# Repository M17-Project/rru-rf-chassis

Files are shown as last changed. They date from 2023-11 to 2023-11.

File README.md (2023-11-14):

[][cc-by-nc-sa]

# rru-rf-chassis
Milled aluminum chassis for the [RRU RF board](https://github.com/M17-Project/rru-rf-hw).

## License
This work is licensed under a
[Creative Commons Attribution-NonCommercial-ShareAlike 4.0 International License][cc-by-nc-sa].

[][cc-by-nc-sa]

[cc-by-nc-sa]: http://creativecommons.org/licenses/by-nc-sa/4.0/
[cc-by-nc-sa-image]: https://licensebuttons.net/l/by-nc-sa/4.0/88x31.png
[cc-by-nc-sa-shield]: https://img.shields.io/badge/License-CC%20BY--NC--SA%204.0-lightgrey.svg

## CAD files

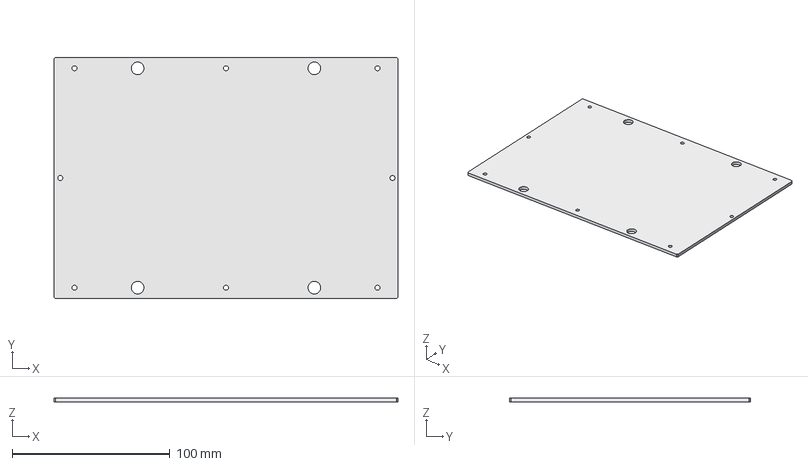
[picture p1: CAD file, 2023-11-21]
lid.step
218.0 x 153.0 x 2.50 mm

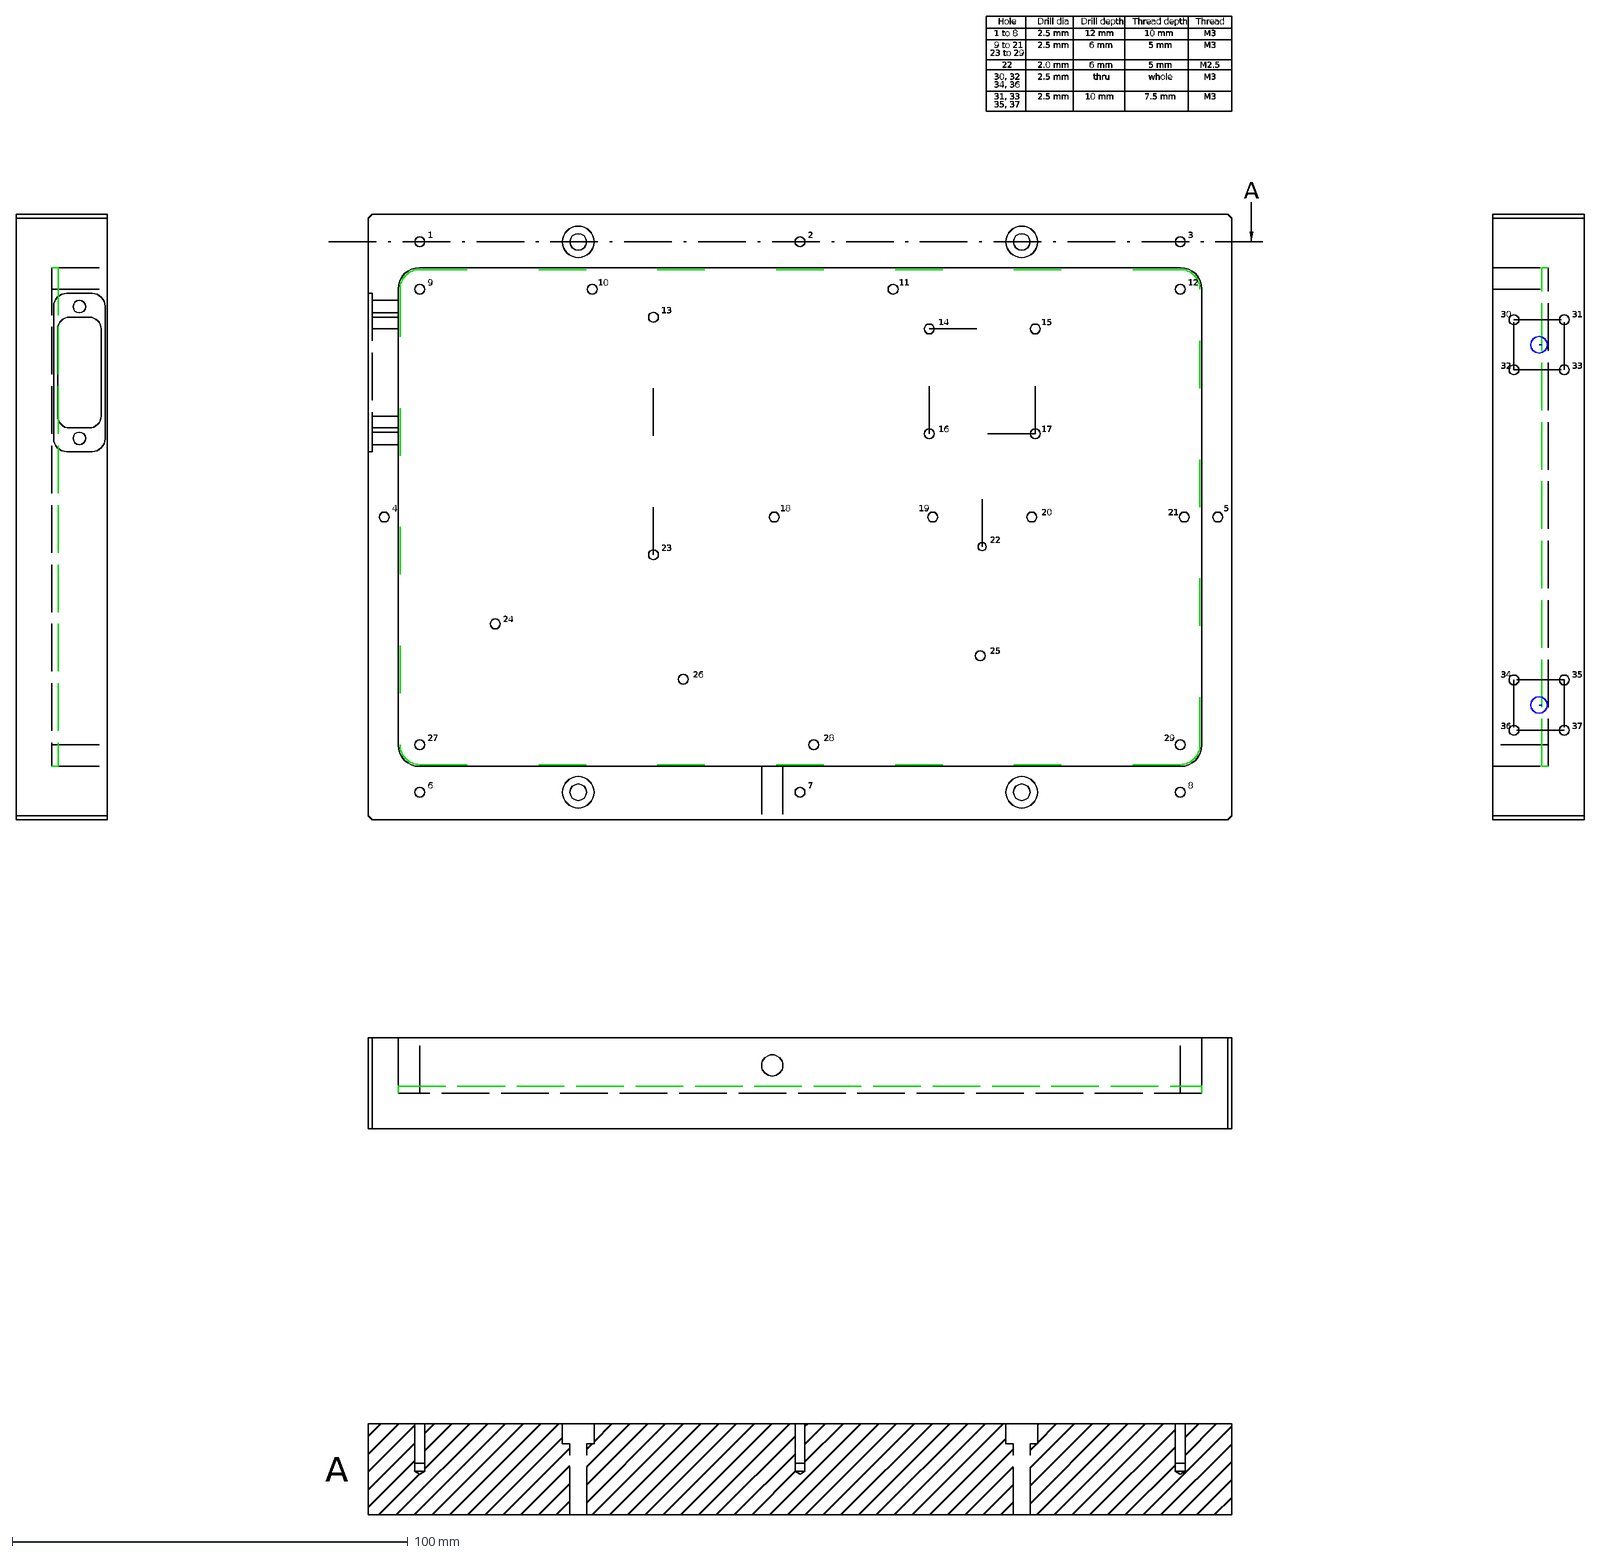
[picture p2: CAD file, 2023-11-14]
base.dxf
A
1
2
3
4
5
6
7
8
9
10
11
12
13
14
15
16
17
23
18
19
20
21
22
24
25
26
27
28
29
30
31
32
33
34
35
36
37
Hole
Drill dia
Drill depth
Thread depth
Thread
1 to 8
2.5 mm
12 mm
10 mm
M3
9 to 21
5 mm
6 mm
23 to 29
30, 32
34, 36
31, 33
35, 37
2.0 mm
M2.5
thru
whole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

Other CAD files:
lid.FCStd
lid.dxf

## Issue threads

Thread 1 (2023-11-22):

DA-15 connector

sp5wwp, 2023-11-22:
The hole for DA-15 connector `DA15S064TLF` needs to be trimmed slightly, it's too small. Dimensions read from Mouser's 3D model are inaccurate. Since the connector can be forced in, I'm tagging this as an `enhancement` instead of `bug`.

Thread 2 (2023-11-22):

Power supply pin

sp5wwp, 2023-11-22:
The power supply feed through capacitor `2499-003-X5W0-103ZLF` fits in nicely but, is not held in place strong enough. The hole needs to be threaded.

Capacitor's pin inside the chassis is short, much less than a millimeter.

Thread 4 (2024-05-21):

M4 mounting bolt depth

sp5wwp, 2024-05-21:
18mm of material below the bolt seems too much. For a standard M4x20 bolt, it leaves only 2mm of thread. Subtracting the gap filled with thermal grease, that leaves less than 2mm. I'd deepen the counterbore hole by 1mm.

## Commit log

2023-11-02 initial upload
    [base.dxf]
2023-11-03 added 4 mounting holes
    [base.dxf]
2023-11-03 update holes
    [base.dxf]
2023-11-03 left side view
    [base.dxf]
2023-11-06 added a hole for DA15 connector
    [base.dxf]
2023-11-06 updated pcb outline
    [base.dxf]
2023-11-07 dimensions update
    added a few threaded holes for the lid
    [base.dxf]
2023-11-08 added missing dimension
    [base.dxf]
2023-11-09 3d render
    [base.dxf]
2023-11-10 added thread data
    [base.dxf]
2023-11-14 cross section A update
    [base.dxf]
2023-11-21 lid design
    [lid.FCStd, lid.dxf, lid.step]

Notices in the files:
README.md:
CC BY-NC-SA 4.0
